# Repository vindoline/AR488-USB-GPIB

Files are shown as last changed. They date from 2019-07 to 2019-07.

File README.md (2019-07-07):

# AR488-USB-GPIB
PCB for AR488 USB-GPIB adapter project.

This board maps out the physical pin mapping required by the AR488 sketch and emluates an Arduino UNO board. The USB interface is implemented with an FTDI FT232RL chip for maximum compatibility. The board requires an ATMEGA328P chip with an Arduino bootloader installed. Placing SW1 in the 'prog' position allows the Arduino IDE to automatically 'reset' the chip for easy upload of sketches. SW1 must be placed in the 'Run' position when using the USB-GPIB adapter.

The Gerbers have been uploaded and shared at OSHPark: https://oshpark.com/shared_projects/zpvaL7rz

For your convienience, a bill of materials has been attached with part numbers from Mouser electronics.

The firmware is located at: https://github.com/Twilight-Logic/AR488
Comments and feedback can be provided here: https://www.eevblog.com/forum/projects/ar488-arduino-based-gpib-adapter/
Based on original work by Emanuele Girlando: http://egirland.blogspot.com/2014/03/arduino-uno-as-usb-to-gpib-controller.html

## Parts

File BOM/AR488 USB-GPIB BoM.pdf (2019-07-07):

AR488 USB-GPIB
Mouser # | Mfr. # | Manufacturer Customer # Description | Order Qty. Price (USD) Ext.: (USD)
895-FT232RL-TUBE | FT232RL-TUBE | FTDI | U2 | USB Interface IC FT232R Single Ch Full Speed | 1 | $4.50 | $4.50
556-ATMEGA328P-PU | ATMEGA328P-PU | Microchip | U1 | 8-bit Microcontrollers - MCU 32KB In-system Flash 20MHz 1.8V-5.5V | 1 | $2.14 | $2.14
538-54819-0519 | 54819-0519 | Molex | J1 | USB Connectors USB Mini-B Recept On-The-Go Rt.Angle | 1 | $1.60 | $1.60
636-111-024-113L001 | 111-024-113L001 | NorComp | CON1 | I/O Connectors 24P Centronics male solder cup | 1 | $5.18 | $5.18
81-BL01RN1A1D2B | BL01RN1A1D2B | Murata | L1 | Ferrite Beads AXIAL 7000mA EMIFIL | 1 | $0.22 | $0.22
653-B3F-1000-S | B3F-1000S | Omron | RESET | Tactile Switches 6x6 Flat 4.3mm Btn Force 100g w/o Grd | 1 | $0.32 | $0.32
559-FOXS160-20-LF | FOXSLF/160-20 | Fox | XL | Crystals 16MHz 20pF | 1 | $0.34 | $0.34
75-1C10C0G220J050B | 1C10C0G220J050B | Vishay | C1,C2 | Multilayer Ceramic Capacitors MLCC - Leaded 22pF 50volts C0G 5% 2.5mm L/S | 2 | $0.18 | $0.36
581-TAJB106K020RNJV | TAJB106K020RNJV | AVX | C3 | Tantalum Capacitors - Solid SMD 20V 10uF 10% 1210 ESR= 2.1 Ohms | 1 | $0.18 | $0.18
604-WP3A8GD | WP3A8GD | Kingbright | TX | Standard LEDs - Through Hole Green 568nm Diffused 20mcd | 1 | $0.26 | $0.26
604-WP132XYT | WP132XYT | Kingbright | RX | Standard LEDs - Through Hole YELLOW TRANSPARENT | 1 | $0.27 | $0.27
594-MBB02070C3300FCT | MBB02070C3300FCT00 | Vishay | R2,R3 | Thin Film Resistors - Through Hole .6w 330ohms 1% | 2 | $0.11 | $0.22
594-MBB02070C1002FRP | MBB02070C1002FRP00 | Vishay | R1 | Thin Film Resistors - Through Hole .6w 10Kohms 1% | 1 | $0.10 | $0.10
633-SS12SDP2 | SS12SDP2 | NKK Switches SW1 | Slide Switches SPDT ON-NONE-ON TOP | 1 | $1.49 | $1.49
77-VJ1206A103JXATBC | VJ1206A103JXATW1BC | Vishay | C4 | Multilayer Ceramic Capacitors MLCC - SMD/SMT 1206 0.01uF 50volts C0G 5% | 1 | $0.26 | $0.26
810-CGA5L2C0G1H104J | CGA5L2C0G1H104J160AA TDK | C5,C6,C7,C8 Multilayer Ceramic Capacitors MLCC - SMD/SMT CGA 1206 50V 0.1uF C0G 5% AEC-Q200 | 4 | $0.53 | $2.12
Total: | $19.56

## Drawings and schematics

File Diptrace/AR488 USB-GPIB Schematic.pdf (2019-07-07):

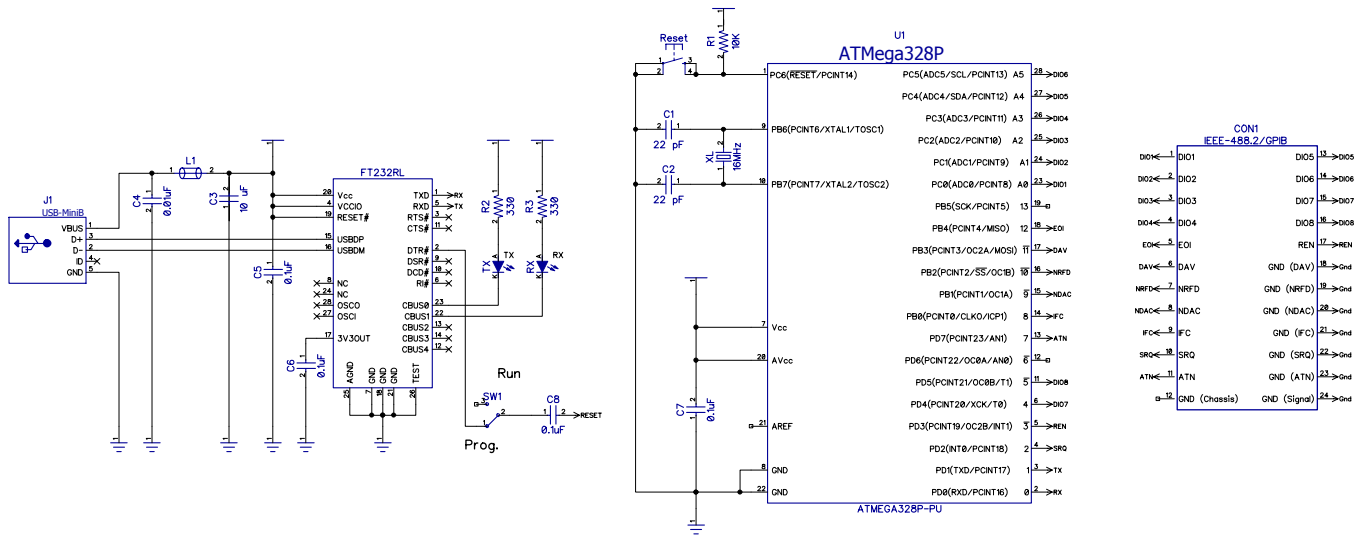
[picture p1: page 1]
USB-MiniB; ATMega328P
